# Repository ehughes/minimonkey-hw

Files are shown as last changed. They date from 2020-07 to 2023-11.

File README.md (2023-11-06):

# Mini Monkey - Hardware #

This repo has the PCB design data for the Mini-Monkey that is based upon the LPC55S69 in a VFBGA98 package.     Each PCB revision is in its own folder.  I typically always keep copies of all revisions in one repo so I can have access to multiple CCA versions at one time (instead of branches for each PCB/CCA).   Branches are used for development and merged into master when boards are sent out.

The Mini-Monkey is in a prototype state.   Use at your own risk.

### Latest Revision - Navigation ###

The latest revision is PCB Rev C. 

The design files are in Altium v20 format.

### History/Notes

#### PCB REV C:

- Added SD/eMMC Storage
- Fixed battery charger and added USB bypass.
- Added RS-485 Interface 

#### PCB REV B:

- Switched to using USB1 as the ROM bootloader is easier to use out of the box
- Fixed RST connection issue from REV A.
- There is now UART connections to the IO Pins.  Using the UART that also always for ISP Boot.
- Move the RST button to make ISP entry easier for humans
- Added some test points.

*Note:  there are still some issues with the battery/charger on REV B.  See the "bug" on the schematics.    It is usable but will be improved in the future.*

#### PCB Rev A:

- Included for historical purposes.  This is just an assembly test run @ MacroFab.

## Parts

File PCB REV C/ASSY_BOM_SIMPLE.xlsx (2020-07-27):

 |  |  |  | Assembly BOM | Field=CCA_PART_NUMBER
 |  |  |  | Rev: | Field=VariantName
 |  |  |  | Description: | Field =PROJECT_TITLE_LINE_1
Column = Fitted | Column = Line # | Column=Quantity | Column=Designator | Column=Description | Column=Manufacturer | Column=Manufacturer Part Number | Column = Substitution Notes

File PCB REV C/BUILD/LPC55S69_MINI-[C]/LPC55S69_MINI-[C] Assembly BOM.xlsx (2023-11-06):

 |  |  |  | Assembly BOM | LPC55S69_MINI
 |  |  |  | Rev: | C
 |  |  |  | Description: | LPC55S69_MINI
Fitted | Line # | Quantity | Designator | Description | Manufacturer | Manufacturer Part Number | Substitution Notes
Fitted |  | 1 | U3 | 1.54" 240x240 IPS Display | Buy Display | ER-TFT1.54-1
Fitted |  | 1 | U6 | 20Hz ~ 10kHz Digital, I²S Microphone MEMS (Silicon) 1.8V Omnidirectional (-26dB ±3dB @ 94dB SPL) Solder Pads | Knowles Acoustics | SPH0645LM4H-B
Fitted |  | 1 | U1 | Charge Controller Li-Ion/Li-Pol 15mA to 500mA 4.2V 5-Pin SOT-23 T/R | Microchip | MCP73832T-2ATI/OT
Fitted |  | 1 | U7 | Crystal 16MHz ±20ppm (Tol) ±50ppm (Stability) 18pF FUND 50Ohm 2-Pin CSMD T/R | Abracon | ABM3-16.000MHZ-B2-T
Fitted |  | 1 | L2 | FERRITE BEAD 220 OHM 0402 1LN | Taiyo Yuden | BKP1005EM221-T
Fitted |  | 1 | L1 | FIXED IND 4.7UH 520MA 650 MOHM | Taiyo Yuden | CBC2012T4R7M
Fitted |  | 1 | U5 | IC MCU 100MHZ CORTEX M33 DUAL | NXP Semiconductors | LPC55S69JEV98K
Fitted |  | 1 | U2 | IC REG LINEAR 3.3V 300MA SOT23-5 | Microchip | MCP1802T-3302I/OT
Fitted |  | 1 | U8 | IC TXRX RS422/485 20MBPS 10MSOP | Intersil | ISL3176EIUZ-T
Fitted |  | 1 | Q2 | MOSFET N-CH 20V 0.9A SOT-23 | Fairchild Semiconductor | FDV305N
Fitted | 1 | 7 | C5, C7, C8, C9, C11, C12, C13 | CAP CER 0.1UF 16V X7R 0402 | TDK Corporation | CGA2B1X7R1C104K050BC | 0.1µF , 16V , ±10% , X7R , -55°C ~ 125°C , AEC-Q200 , 0402
Fitted | 2 | 2 | R9, R10 | RES 1K OHM 1/10W 1% 0402 SMD | Panasonic Electronic Components | ERJ-2RKF1001X | 1k , ±1% , 0402 , AEC-Q200
Fitted | 3 | 5 | C1, C2, C3, C4, C10 | CAP CER 10UF 6.3V X7R 0805 | TDK Corporation | CGA4J1X7R0J106K125AC | 10µF , 6.3V , ±10% , X7R , -55°C ~ 125°C , AEC-Q200 , 0805
Fitted | 4 | 6 | R1, R3, R4, R7, R8, R11 | RES 10K OHM 1/10W 1% 0402 SMD | Panasonic Electronic Components | ERJ-2RKF1002X | 10k , ±1% , 0402 , AEC-Q200
Fitted | 6 | 2 | C14, C15 | CAP CER 18PF 50V C0G 0402 | TDK Corporation | CGA2B2C0G1H180J050BA | 18pF , 50V , ±5% , C0G, NP0 , -55°C ~ 125°C , AEC-Q200 , 0402
Fitted | 7 | 2 | R5, R6 | RES 33 OHM 1/10W 1% 0402 SMD | Panasonic Electronic Components | ERJ-2RKF33R0X | 33 , ±1% , 0402 , AEC-Q200
Fitted | 8 | 1 | R2 | RES 33 OHM 1/10W 1% 0603 SMD | Panasonic Electronic Components | ERJ-3EKF33R0V | 33 , ±1% , 0603 , AEC-Q200
Fitted | 9 | 1 | C6 | CAP CER 47PF 50V C0G 0402 | TDK Corporation | CGA2B2C0G1H470J050BA | 47pF , 50V , ±5% , C0G, NP0 , -55°C ~ 125°C , AEC-Q200 , 0402
Fitted | 10 | 1 | R12 | RES 100 OHM 1/10W 1% 0603 SMD | Panasonic Electronic Components | ERJ-3EKF1000V | 100 , ±1% , 0603 , AEC-Q200
Fitted | 11 | 4 | BTN1, BTN2, BTN3, RESET | SWITCH TACTILE SPST-NO 0.05A 12V | Omron Electronics Inc-EMC Div | B3U-1100P
Fitted | 12 | 3 | D1, D2, D3 | DIODE SCHOTTKY 30V 1A SOD323 | Diodes Inc | BAT760-7
Fitted | 15 | 1 | SW1 | NIDEC COPAL ELECTRONICS - CHS-01TA - DIP SWITCH, 1POS, SPST, SLIDE, SMD | Nidec Copal | CHS-01TA
Fitted | 16 | 1 | J4 | CONN MICRO SD R/A PUSH-PUSH SMD | Hirose Electric Co Ltd | DM3AT-SF-PEJM5
Fitted | 18 | 1 | J3 | SAMTEC - FTSH-105-01-F-DV - .050 X .050 | SAMTEC | FTSH-105-01-F-DV
Fitted | 23 | 1 | Q1 | MOSFET P-CH 20V 1A SOT-23 | ON Semiconductor | NTR1P02T1G
Fitted | 24 | 1 | U4 | TVS DIODE 5.5VWM SOT143B | NXP Semiconductors | PRTR5V0U2X,215
Fitted | 25 | 1 | J1 | CONN HEADER PH SIDE 2POS 2MM SMD | JST Sales America Inc | S2B-PH-SM4-TB(LF)(SN)
Fitted | 27 | 1 | J2 | CONN RCPT STD MICRO USB TYPE B | FCI | 10103594-0001LF

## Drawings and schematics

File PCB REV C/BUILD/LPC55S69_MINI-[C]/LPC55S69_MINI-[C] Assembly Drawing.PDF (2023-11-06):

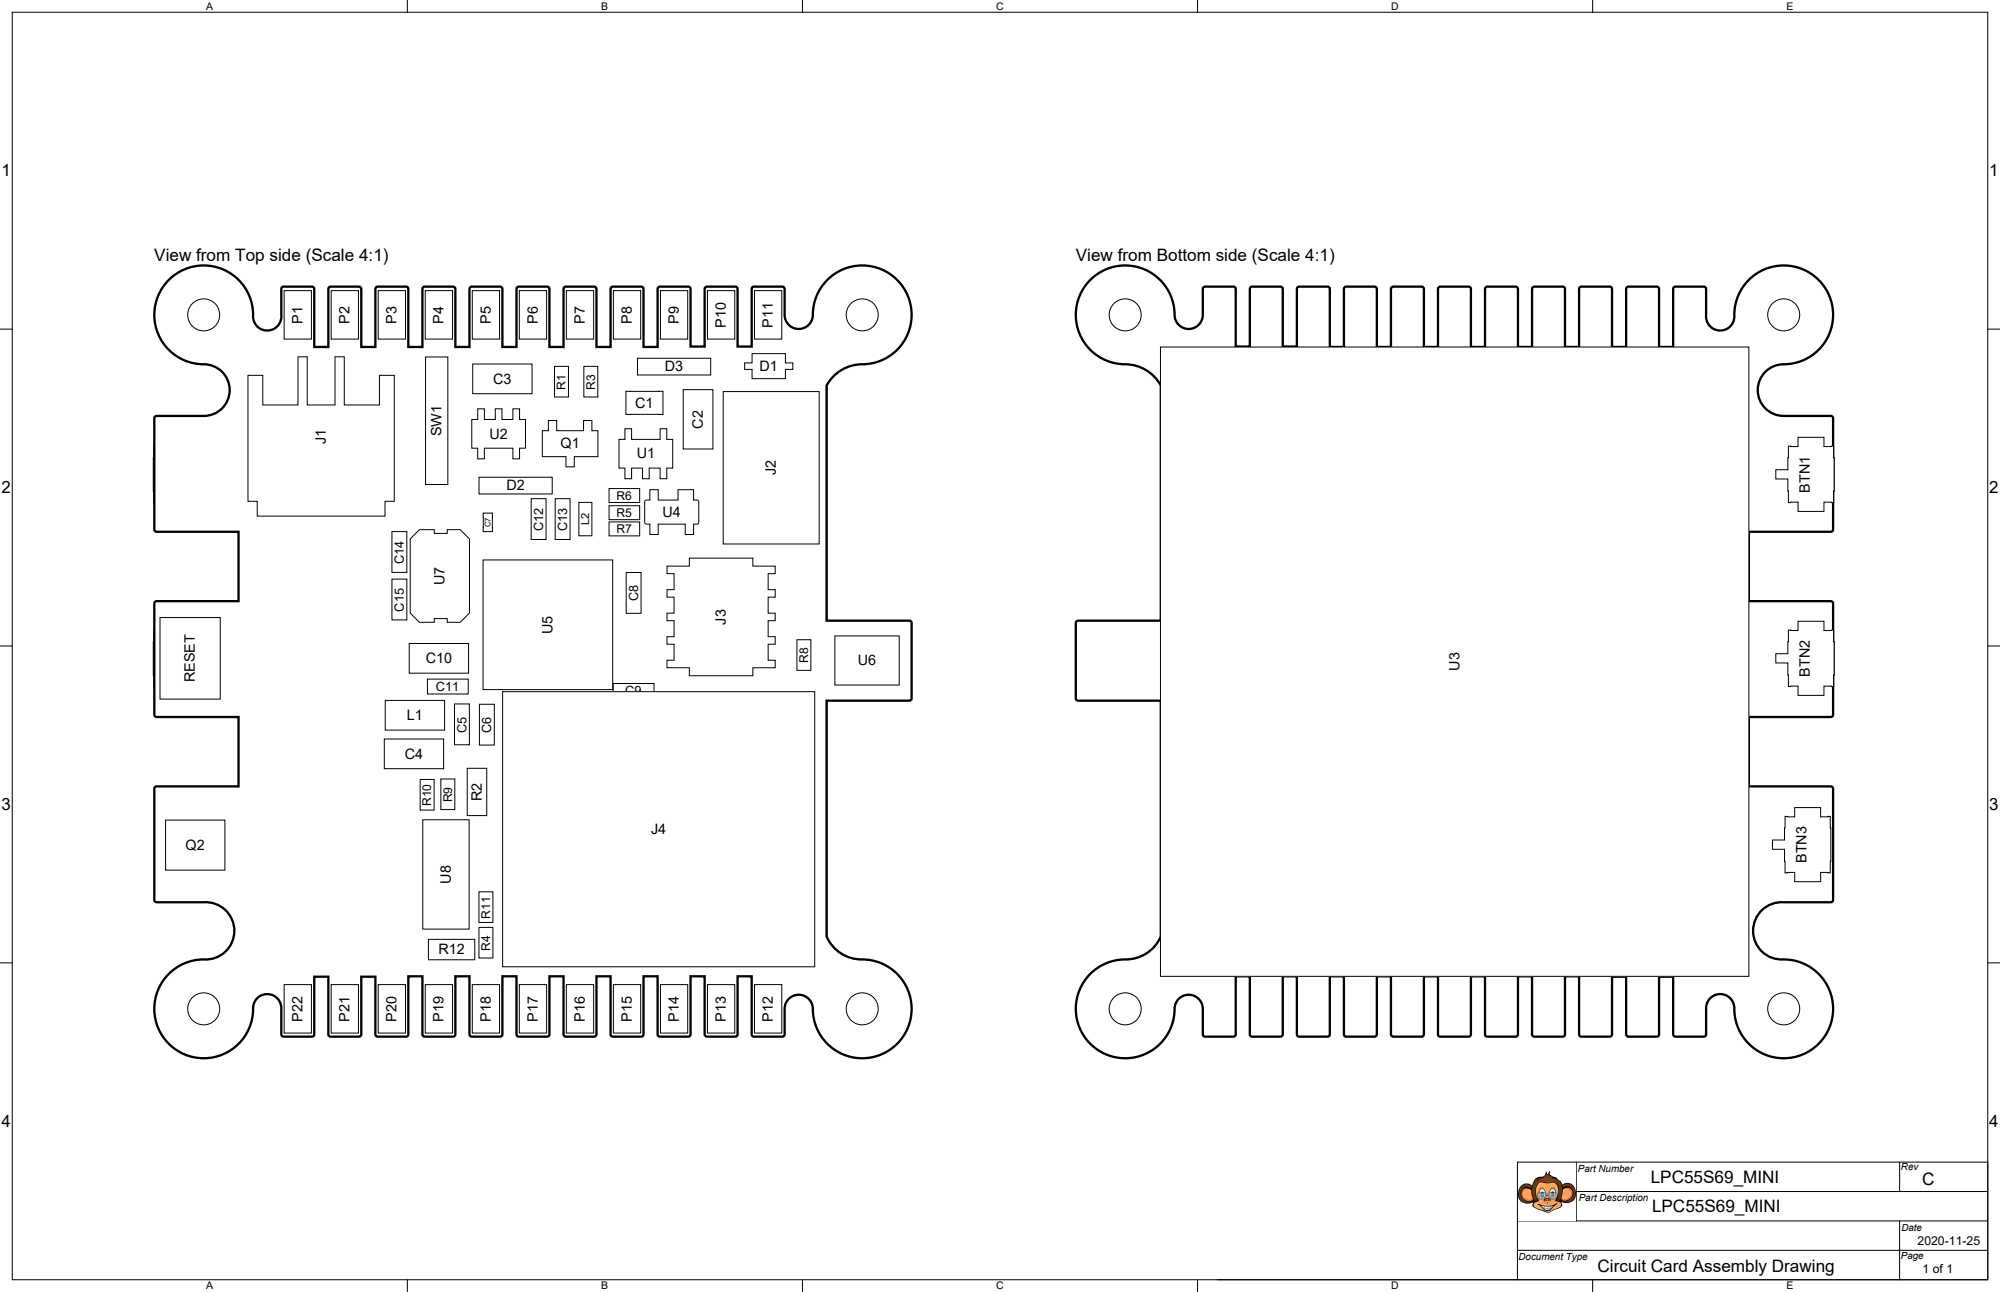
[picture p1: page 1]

View from Top side (Scale 4:1)

View from Bottom side (Scale 4:1)

Circuit Card Assembly Drawing

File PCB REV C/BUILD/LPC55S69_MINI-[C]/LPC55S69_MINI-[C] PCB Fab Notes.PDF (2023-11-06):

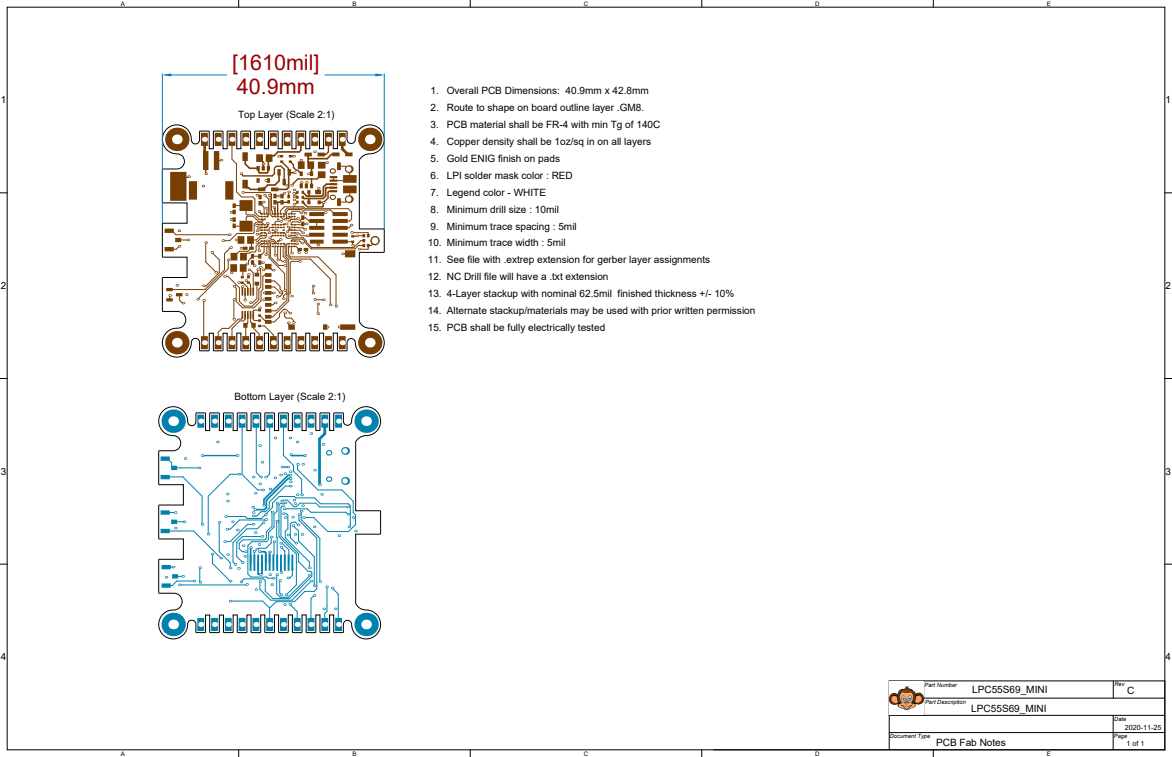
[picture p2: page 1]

1. Overall PCB Dimensions: 40.9mm x 42.8mm
2. Route to shape on board outline layer .GM8.
3. PCB material shall be FR-4 with min Tg of 140C
4. Copper density shall be 1oz/sq in on all layers
5. Gold ENIG finish on pads
6. LPI solder mask color : RED
7. Legend color - WHITE
8. Minimum drill size : 10mil
9. Minimum trace spacing : 5mil
10. Minimum trace width : 5mil
11. See file with .extrep extension for gerber layer assignments
12. NC Drill file will have a .txt extension
13. 4-Layer stackup with nominal 62.5mil finished thickness +/- 10%
14. Alternate stackup/materials may be used with prior written permission
15. PCB shall be fully electrically tested

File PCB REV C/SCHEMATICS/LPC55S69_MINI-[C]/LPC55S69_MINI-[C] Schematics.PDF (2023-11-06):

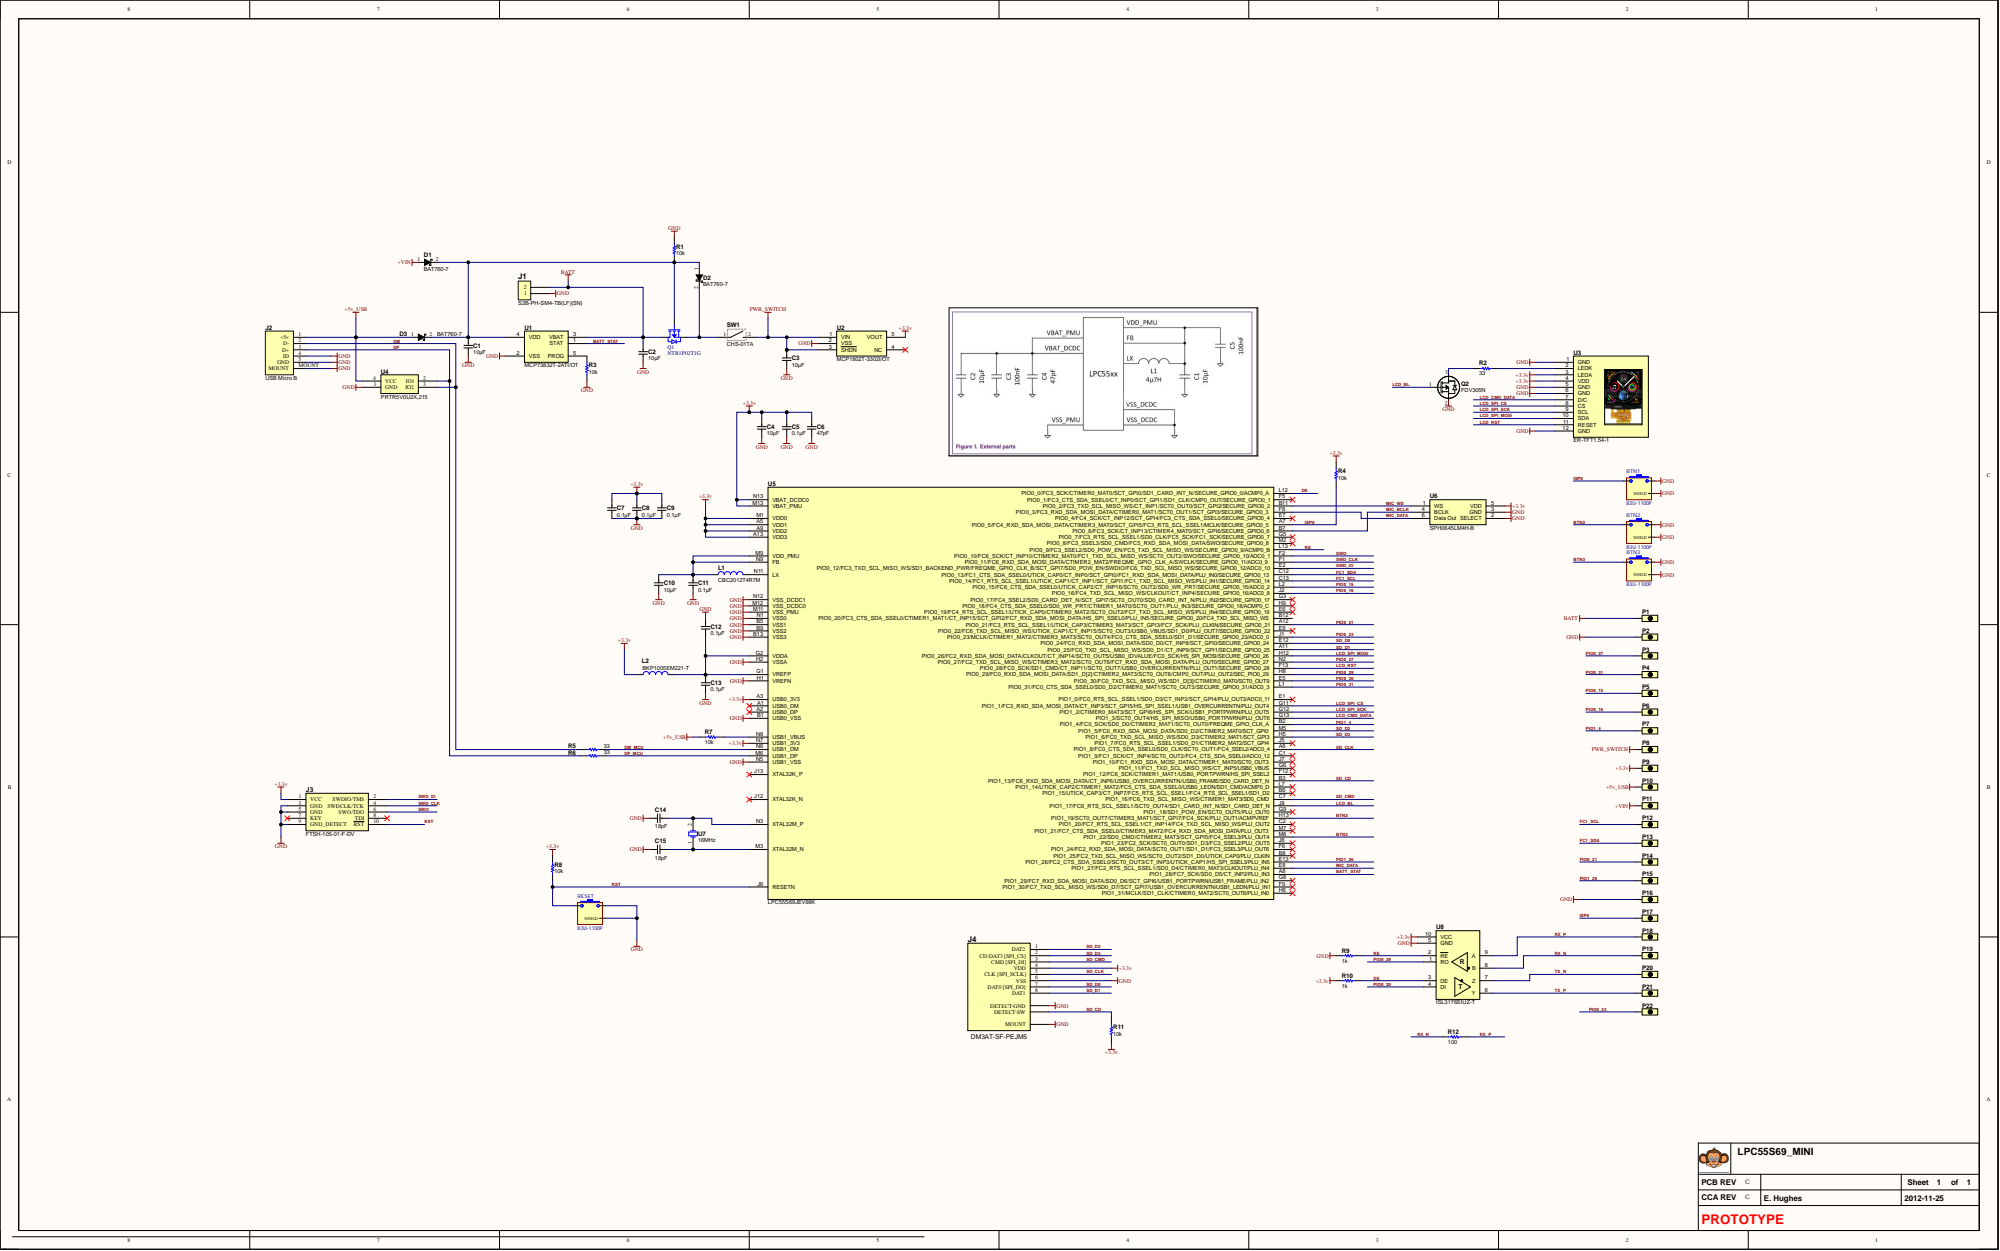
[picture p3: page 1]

ISP0

LPC55S69_MINI C

PC B REV | | Shee t 1 o f 1

C C A REV C | E. Hughes | 2012-11-2 5

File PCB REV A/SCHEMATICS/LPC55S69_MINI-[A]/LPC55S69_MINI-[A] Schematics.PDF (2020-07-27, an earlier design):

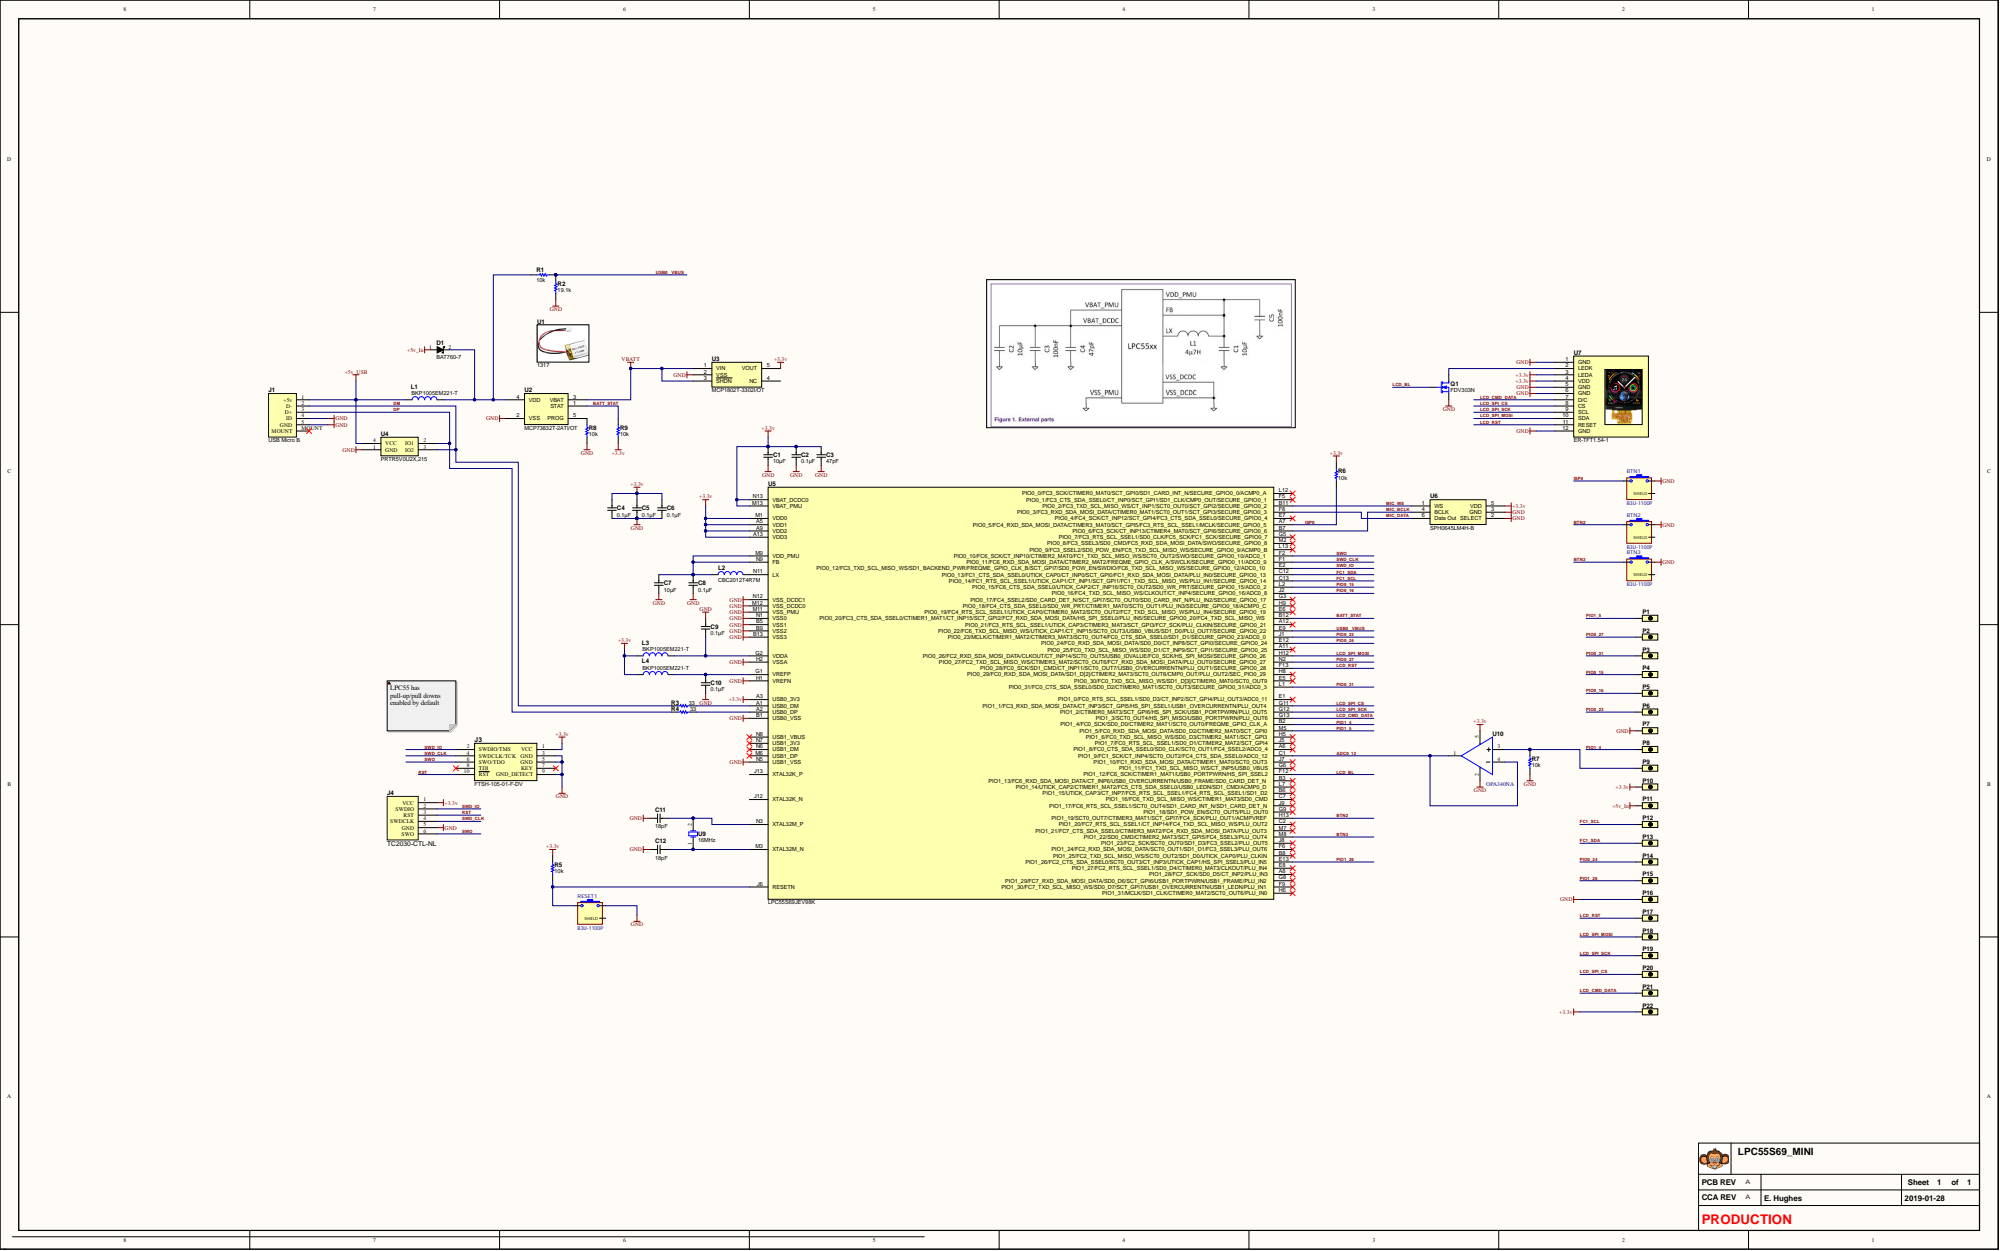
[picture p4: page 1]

4 | U 4

MIC _ D ATA | 6

ISP0

LPC55S69_MINI A

PC B REV | | Sheet 1 of 1

C C A REV A | E. Hughes | 2019-01-28

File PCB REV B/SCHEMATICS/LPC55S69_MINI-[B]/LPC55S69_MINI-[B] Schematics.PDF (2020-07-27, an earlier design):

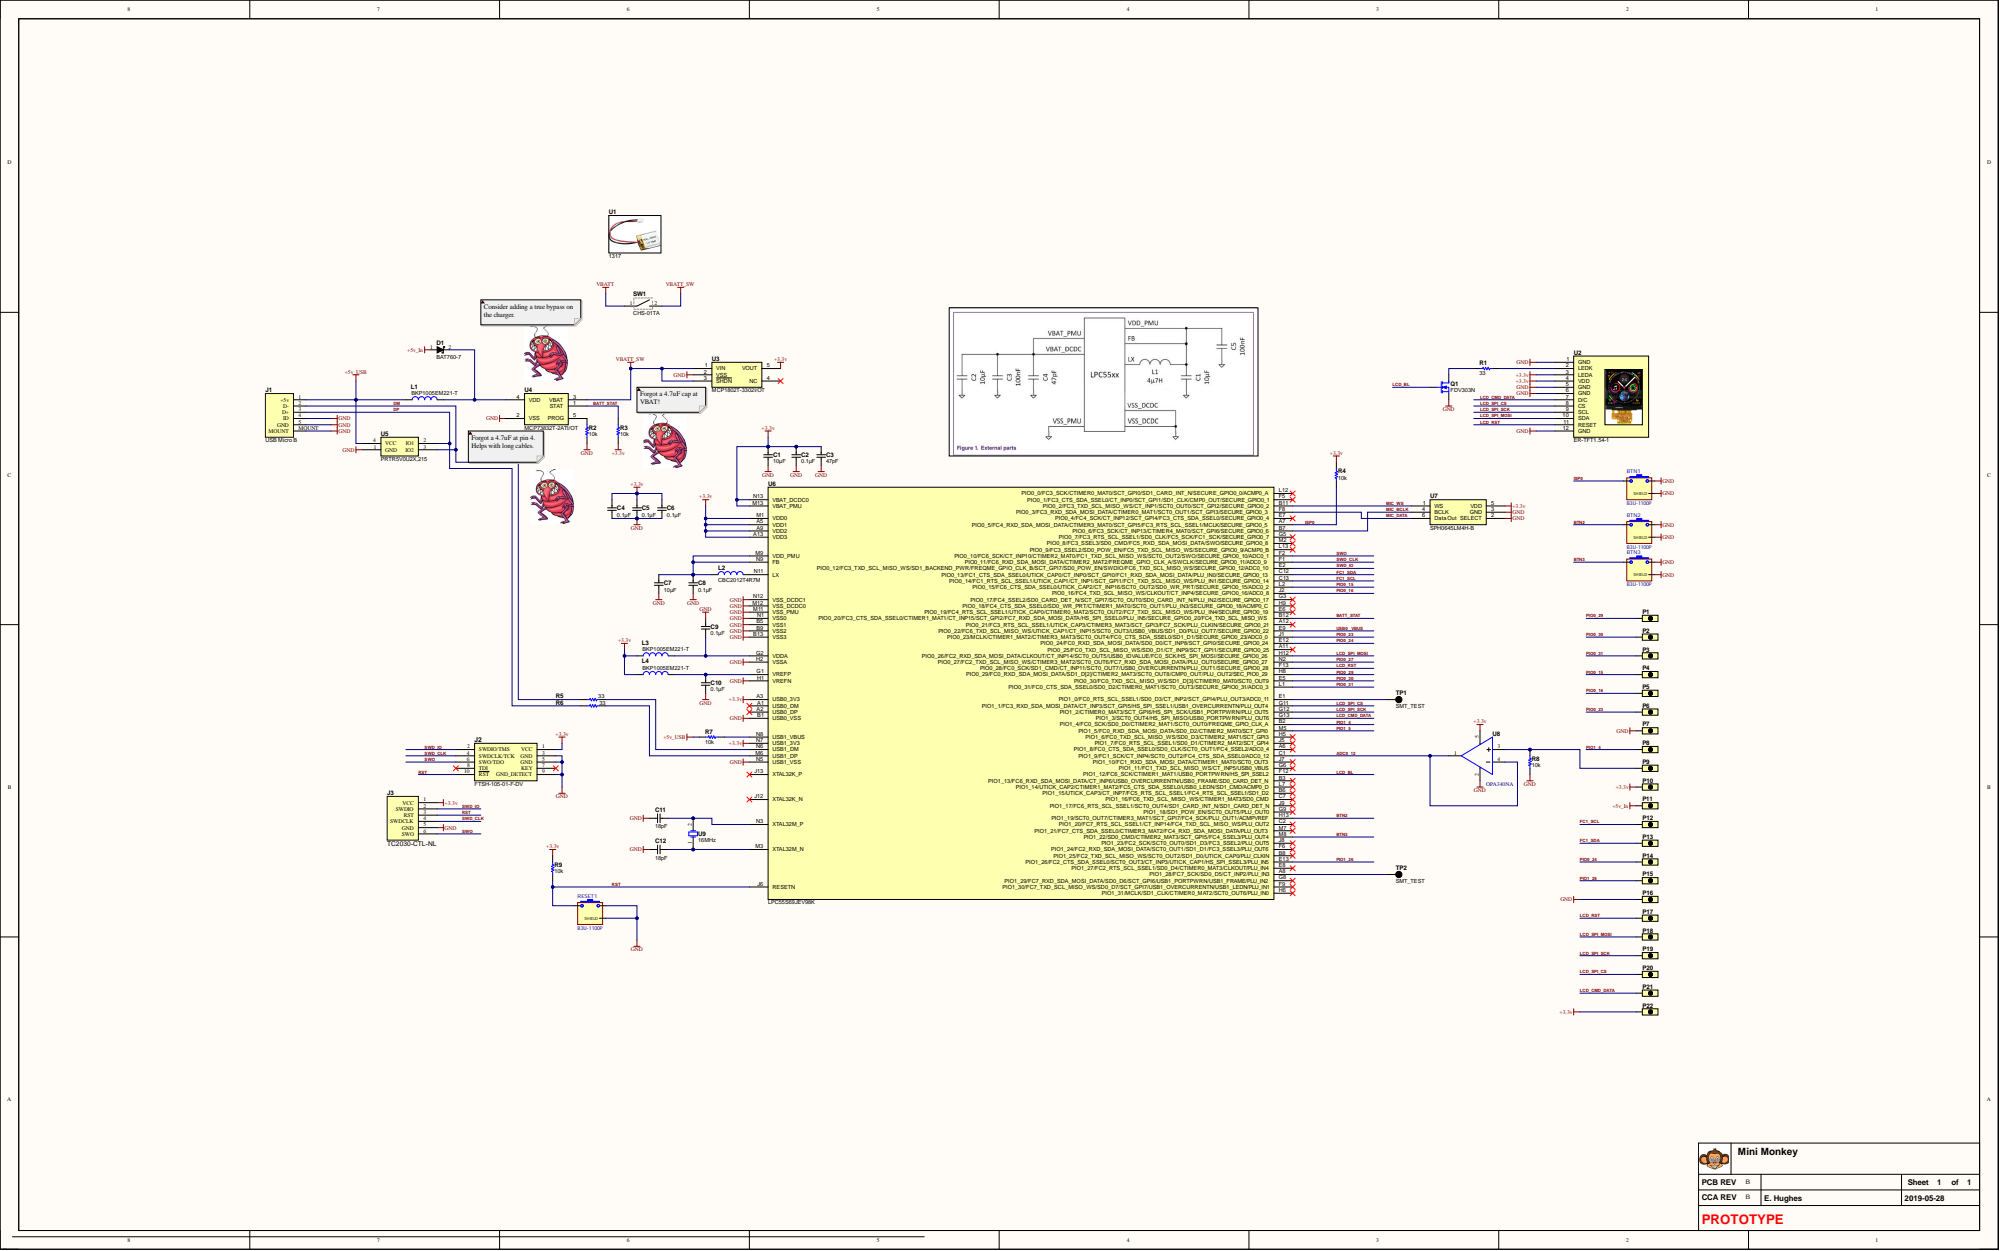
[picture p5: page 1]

M IC_DATA | 6

ISP0

Mini Monkey B

PC B REV | | Shee t 1 o f 1

C C A REV B | E. Hughes | 2019-05-2 8

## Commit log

2020-07-27 1st add
    [ASSY_BOM_SIMPLE.xlsx, LPC55S69_MINI [A].PCBdoc, LPC55S69_MINI [A].PrjPcb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]
2020-08-11 working on placement options
    [ASSY_BOM_SIMPLE.xlsx, LPC55S69_MINI [C].PCBdoc, LPC55S69_MINI [C].PrjPcb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]
2020-11-18 working on Rev C
    [LPC55S69_MINI [C].PCBdoc, LPC55S69_MINI [C].PrjPcb, LPC55S69_MINI.SchDoc]
2020-11-23 Rev C almost ready
    [LPC55S69_MINI [C].PCBdoc, LPC55S69_MINI [C].PrjPcb, LPC55S69_MINI.SchDoc]
2020-11-23 REV C sent to PCB.NG
    [LPC55S69_MINI [B].PCBdoc, LPC55S69_MINI [C].PCBdoc, LPC55S69_MINI [C].PrjPcb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]
2020-12-22 doc updates
    [LPC55S69_MINI [C].PCBdoc, LPC55S69_MINI [C].PrjPcb, LPC55S69_MINI [C]2.PCBdoc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]
2023-11-06 Updated Rev C w/ Mosfet fix
    [LPC55S69_MINI [C].PCBdoc, LPC55S69_MINI [C]2.PCBdoc, LPC55S69_MINI-[C] Assembly BOM.xlsx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]
